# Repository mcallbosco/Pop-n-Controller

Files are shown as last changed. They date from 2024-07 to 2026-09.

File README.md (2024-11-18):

# Pop-n-Controller
THIS IS NOT READY. This repo focuses on the construction of a pop'n controller using a 3d printer and laser cutter. A remix of https://github.com/charcole/Dreamcast-PopnMusic

# Why did I make this
I didn't want to laser cut all the wood that charcole's project required (Especially since the size was too large for my cutter). I did however want a controller with curves. Unfortunetly, it was harder than I thought but now we are here.

# Required things for a pop'n controller of any type.
9 100mm Buttons
    1 Red
    2 Blue
    2 Green
    2 Yellow
    2 White
A Microcontroller
    I recomend the Aurduino Leonardo. It's cheap, easy to use and since our controller doesn't have additional LEDS, it's perfect for use with this controller. I would recomend using https://github.com/CrazyRedMachine/UltimatePopnController as the firmware. 
Wire
    I personally used arcade switch wires for the switches, and soldered on the wires for the lights since I didn't have any of those.

# Things required for this project
Access to a laser cutter
    This is required for the top bit. This could be modified to use 3D printed parts that are segmented, and now that I think about that I probably should add that as an option. But for now, you need a laser cut top part. The top should be made out of a sturdy material, but I got by with 1/8th inch thick ultility board. 
Access to a larger 3D printer.
    I used a neptune 4 plus, and some things hardly managed to fit on the plate. 
That's it
    We will be printing our own bolts/nuts to use, this may seem like a bad idea but it's worked well for my builds of this project. If you want to, you could change the height of the walls and make it compatable with metal bolts/nuts you can get on ebay. This project uses M8 spec nuts and bolts. 

# What should I Print/Make
    Follow the readme in the Things To Make folder.

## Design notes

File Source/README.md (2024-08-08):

Congrats, you want to build upon or modify this project to make it better. Here's a few things you should know.

# Sorry about the mess. This code is very messy, but hopefully most of the things you want to change are avalible as paramaters.
# This code is also extremly unoptimized. Usage of the OpenSCAD nightly is basically required. Enable Manifold. 

# Wall Thickness
# Due to the way I imported the walls, the walls are not 1 to 1 and not evenly thick on all parts. Sorry about this.

# Height Changes
# The bolts should automatically be compensated when you change the height, but I would recomend printing a test one to make sure before going all out.

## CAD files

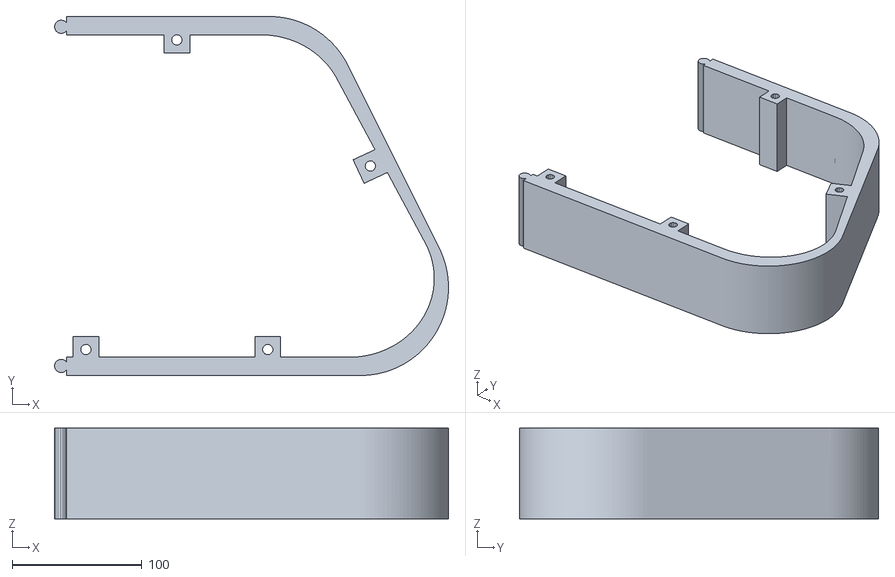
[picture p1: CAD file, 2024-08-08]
Things To Make/Wall3.stl
303.5 x 276.5 x 70.0

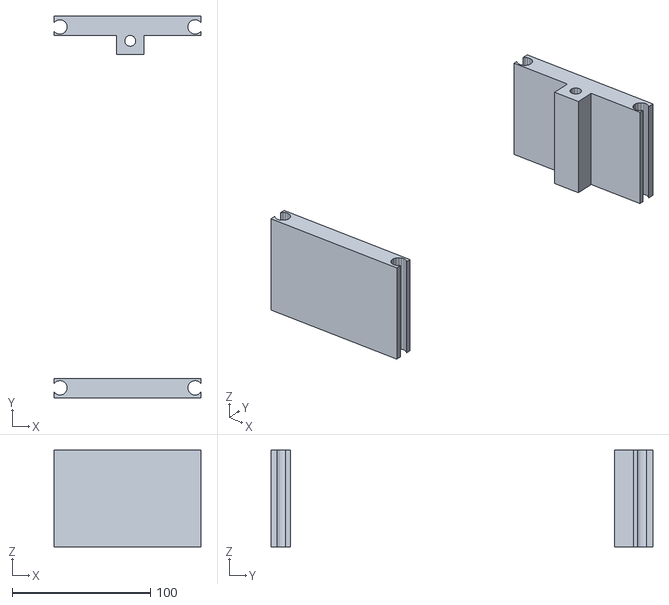
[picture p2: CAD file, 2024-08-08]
Things To Make/Wall2.stl
106.1 x 276.5 x 70.0

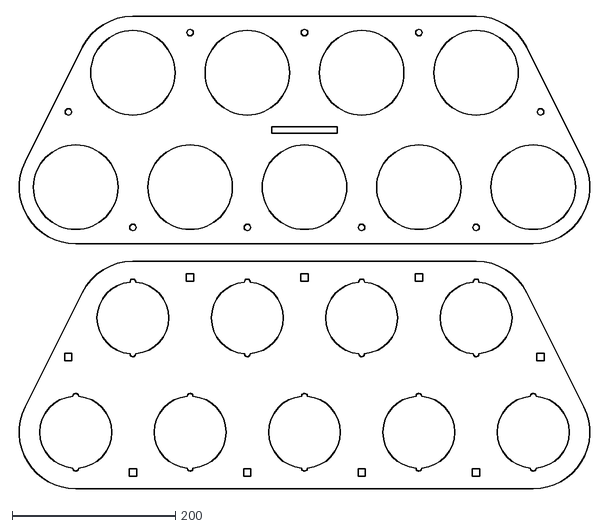
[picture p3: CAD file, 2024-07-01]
Things To Make/PopnMusicTop(OG).dxf
705.3 x 578.5

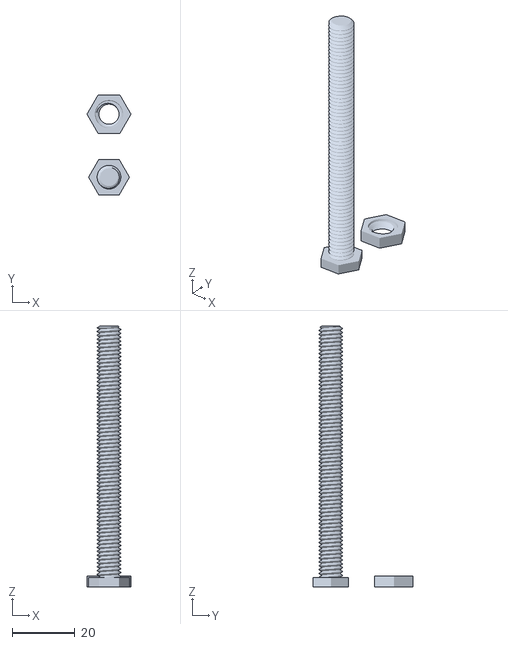
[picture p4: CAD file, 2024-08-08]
Things To Make/NutBolt.stl
14.0 x 31.7 x 82.9

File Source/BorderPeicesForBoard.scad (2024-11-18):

//Outer Shell Generation
mode = 3;
difference(){
union(){
union(){
   for (i = [0:.6:10]){
      //use the imported svg file to generate the wall
      translate([349.2335,138.2555,0]) linear_extrude(.2)
      resize([698.466-i,276.511-(i*.5),0], auto = true)
   import (file = "RefrenceForSpacerSCADdontMake.svg", convexity=3,center = true);

   }
    
    
}
union(){
   for (i = [0:.6:3]){
      //use the imported svg file to generate the wall
      translate([349.2335,138.2555,-4]) linear_extrude(4.2)
      resize([698.466+i,276.511+(i*1.3),0], auto = true)
   import (file = "RefrenceForSpacerSCADdontMake.svg", convexity=3,center = true);

   }
    
    
}
}
union(){
   for (i = [0:.6:.6]){
      //use the imported svg file to generate the wall
      translate([349.2335,138.2555,-2.4+.5]) linear_extrude(.4)
      resize([698.466+i,276.511+(i*1.3),0], auto = true)
   import (file = "RefrenceForSpacerSCADdontMake.svg", convexity=3,center = true);

   }}
   union(){
   for (i = [0:.6:.12 ]){
      //use the imported svg file to generate the wall
      translate([349.2335,138.2555,-2.3+.2]) linear_extrude(.2)
      resize([698.466+i,276.511+(i*1.3),0], auto = true)
   import (file = "RefrenceForSpacerSCADdontMake.svg", convexity=3,center = true);

   }}
union(){
   for (i = [0:.6:1.5]){
      //use the imported svg file to generate the wall
      translate([349.2335,138.2555,-1.5]) linear_extrude(1.5)
      resize([698.466+i,276.511+(i*1.3),0], auto = true)
   import (file = "RefrenceForSpacerSCADdontMake.svg", convexity=3,center = true);

   }}
   if (mode == 1){
translate([279.235+15,-10,-10]) cube ([1000,500,1000]);}
if (mode == 2){
translate([-2,-10,-10]) cube ([279.235+15+2,500,1000]); 
    translate([400.295,-10,-10]) cube ([1000,500,1000]); }
if (mode == 3){
translate([-3,-10,-10]) cube ([400.295+3,500,1000]); 

}
}
    
    
    
    

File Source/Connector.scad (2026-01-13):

// Connector.scad
// Universal connector for joining parts
// Shape: U-channel (Box without top and two faces) with side ridges.

// Generates the 2D profile of the connector (U-shape with side ridges)
module connector_profile(width, height, wall_thickness, base_thickness, ridge_depth) {
    w = width;
    h = height;
    wt = wall_thickness;
    bt = base_thickness;
    rd = ridge_depth;
    
    // Centered on X, Bottom at Y=0 (in 2D) -> Z=0 in 3D
    // U-shape body
    difference() {
        translate([-w/2, 0]) square([w, h]);
        translate([-w/2 + wt, bt]) square([w - 2*wt, h + 0.1]); // +0.1 to ensure top cut
    }
}

// Generates the 3D connector object
module UniversalConnector(length=20, width=8, height=4, wall_thickness=2.5, base_thickness=3.0, ridge_depth=0.5, tolerance=0) {
    // Apply tolerance to shrink the connector slightly if needed
    // Usually tolerance is 0 for the part, and >0 for the hole.
    
    eff_w = width - tolerance;
    eff_h = height - tolerance;
    eff_l = length - tolerance; 
    
    // Extrude along Y
    rotate([-90, 0, 0])
    linear_extrude(height=eff_l, center=true)
        connector_profile(eff_w, eff_h, wall_thickness, base_thickness, ridge_depth);
}

// Generates the negative volume to subtract from the parts
module UniversalConnectorCutout(length=20, width=8, height=4, wall_thickness=2.5, base_thickness=3.0, ridge_depth=0.5, tolerance=0.2) {
    // Cutout is larger by tolerance
    eff_w = width + tolerance;
    eff_h = height; // Height usually matches surface, or +tolerance if embedded
    eff_l = length + tolerance;
    
    // Extrude along Y
    rotate([-90, 0, 0])
    linear_extrude(height=eff_l, center=true)
    connector_profile(eff_w, eff_h, wall_thickness, base_thickness, ridge_depth);
}

// ===================================
// == Z-Pillar and Tab Modules
// ===================================

// A vertical tab that protrudes from the face of a part (Z direction)
// Designed as a radial spoke.
// centered at origin locally, but positioned radially.
module ZTab(width=8, thickness=3, height=8, angle=0, distance=8) {
    // width: Radial length of the tab
    // thickness: Tangential thickness
    // distance: Radial distance from center to center of tab
    // angle: Angle in XY plane
    
    rotate([0, 0, angle])
    translate([distance, 0, 0])
    linear_extrude(height=height, scale=[0.9, 0.9]) // Slight taper for fit
        square([width, thickness], center=true);
}

// The Hub/Pillar that accepts the tabs
// Centered at the intersection point.
module PillarBlock(height=10, radius=14, tab_width=8, tab_thickness=3, tab_dist=8, tolerance=0.3) {
    difference() {
        // Main body - Octagon for style or Cylinder
        cylinder(r=radius, h=height, $fn=8);
        
        // Subtract slots for tabs at 45, 135, 225, 315
        // Add tolerance to the slot
        for (a = [45, 135, 225, 315]) {
             // Slot is slightly larger than tab
             ZTab(width=tab_width + tolerance, thickness=tab_thickness + tolerance, height=height+1, angle=a, distance=tab_dist);
        }
        
        // Central hole for looks or reinforcement?
        // cylinder(r=4, h=height*3, center=true, $fn=16);
    }
}

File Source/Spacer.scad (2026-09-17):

use <Connector.scad>

//=====================================================================
//== Configuration for Splitting and Printing
//=====================================================================

// Set which part to render for export.
// Part 0:     ALL PARTS - Assembly view showing all parts at once
// Bottom Row: 1=Left, 2=Mid-Left, 3=Middle, 4=Mid-Right, 5=Right
// Top Row:    6=Left, 7=Mid-Left, 8=Mid-Right, 9=Right
// Part 10 is the printable connector.
// Part 11 is a test wall connector rail (for fit testing).
part_to_render = 0; // [0:11]

// Assembly view spacing (only used when part_to_render = 0)
// Set to 0 to see parts fully assembled, increase to separate them
assembly_spacing = 10; // Gap between parts in mm

// --- Main Dimensions ---
// Set bottom_plate_mode to true for a simple 5mm plate with no button holes.
bottom_plate_mode = true;

main_wall_height = 70;
main_bottom_height = 8;

wall_thickness = 18; 
wall_height = bottom_plate_mode ? 5 : main_wall_height;
bottom_height = bottom_plate_mode ? 5 : main_bottom_height;

// Locating lip on the wall, with a matching groove in the removable plate.
locating_lip_enabled = true;
locating_lip_height = 1.5;
locating_lip_width = 1.5;
locating_lip_inset = 1.2;     // Outer edge of lip measured from body perimeter
locating_lip_clearance = 0.3; // Clearance on EACH side of the lip
locating_lip_depth_clearance = 0.2;

total_x = 698.466;
total_y = 276.511;
total_z = max(100, wall_height + locating_lip_height + 1, bottom_height + 1);


wall_cuts = [[139.239, 279.235, 419.231, 559.228],
             [209.237, 349.233, 489.230]];
plate_cut_shift = 15;
cut_shift = bottom_plate_mode ? plate_cut_shift : 0;
row_cuts = [for (row = wall_cuts) [for (x = row) x + cut_shift]];
y_cut1 = total_y / 2;

function part_row(part) = part <= 5 ? 0 : 1;
function part_index(part) = part <= 5 ? part - 1 : part - 6;
function row_edges(row) = concat([0], row_cuts[row], [total_x]);
function get_seam_y(x) =
    x < row_cuts[1][0] || x >= row_cuts[1][2] ? y_cut1 - 4 : y_cut1 + 13;

module front_row_volume() {
    // Keep seam faces in 3D: a 2D polygon rounds coordinates before extrusion,
    // which can leave a microscopic gap where a dovetail meets the seam.
    bands = [0, row_cuts[1][0], row_cuts[1][2], total_x];
    for (i = [0:2])
        translate([bands[i], 0, 0])
            cube([bands[i + 1] - bands[i],
                  y_cut1 + (i == 1 ? 13 : -4), total_z]);
}

module part_volume(part) {
    row = part_row(part);
    index = part_index(part);
    edges = row_edges(row);
    intersection() {
        translate([edges[index], 0, 0])
            cube([edges[index + 1] - edges[index], total_y, total_z]);
        if (row == 0) front_row_volume();
        else difference() {
            cube([total_x, total_y, total_z]);
            front_row_volume();
        }
    }
}

// --- Connector Parameters ---
conn_len = 30;
conn_width = 10;
conn_height = 5;
conn_z_pos = bottom_height + (bottom_plate_mode ? 1 : 0); // Flush with top of plate, shifted 1mm up in bottom_plate_mode

// Seam connector positions
conn_middle_x_positions = [70, 100, 140, 175, 210, 245, 280, 315, 350,
                           385, 420, 455, 490, 525, 560, 595, 630];
conn_bottom_y_positions = [45, 110];
conn_top_y_positions = [180, 235];

// --- Wall Connector Parameters (Dovetail Rail/Slot) ---
wall_rail_height = wall_height; // Matches wall height
wall_rail_base = 8;          // Widest part of the dovetail
wall_rail_tip = 4;           // Narrowest part of the dovetail (at the neck)
wall_rail_depth = 4;         // Length of the dovetail pin
wall_rail_tolerance = 0.3;   // Clearance for 3D printing fit
wall_center_offset = 7;      // Distance from outer wall edge to center of connector
side_wall_offset = 32;       // Fixed side connector X offset; check if thickness changes
side_wall_rail_base = 6;     // Smaller base for side walls
side_wall_rail_tip = 3;      // Smaller tip for side walls

// --- USB Connector Hole Parameters ---
usb_hole_diameter = 24;      // Diameter of the USB connector hole (in mm)
usb_x_pos = 330;             // X position (centered on the model by default)
usb_z_pos = 40;              // Z position (height from the bottom, centered on wall)

// D-Type screw hole parameters (Neutrik D-series)
usb_screw_hole_diameter = 3.4; // Diameter for M3 heat-set inserts
usb_screw_x_spacing = 19;      // Horizontal distance between screw centers
usb_screw_z_spacing = 24;      // Vertical distance between screw centers

// Module to create USB connector hole cutout on the back wall
module usb_connector_hole() {
    // Extend beyond the inside wall so the socket always cuts through.
    wall_y = total_y;
    cut_depth = max(30, wall_thickness + 2);
    
    // Main 24mm opening
    translate([usb_x_pos, wall_y - cut_depth/2, usb_z_pos])
    rotate([90, 0, 0])
    cylinder(h = cut_depth, d = usb_hole_diameter, center = true, $fn = 64);

    // D-Type mounting holes (diagonal pair 1: top-left and bottom-right)
    // Horizontal offset: 19/2 = 9.5mm, Vertical offset: 24/2 = 12mm
    for (offset = [[-usb_screw_x_spacing/2, usb_screw_z_spacing/2], 
                   [usb_screw_x_spacing/2, -usb_screw_z_spacing/2]]) {
        translate([usb_x_pos + offset[0], wall_y - cut_depth/2, usb_z_pos + offset[1]])
        rotate([90, 0, 0])
        cylinder(h = cut_depth, d = usb_screw_hole_diameter, center = true, $fn = 32);
    }
}


// --- Magnet Hole Parameters ---
magnet_enabled = true;
magnet_diameter = 6.2;
magnet_depth = 2;
magnet_pitch = 40;             // Approximate pitch before seam exclusions
magnet_end_margins = [90, 165]; // Keep pockets on the straight front/back walls
magnet_edge_clearance = 2;     // Minimum material around a pocket
magnet_seam_clearance = 12;    // Minimum center distance from BOTH sets of cuts
magnet_row_inset = wall_thickness / 2;

function magnet_x_positions(row) =
    let(start = magnet_end_margins[row], end = total_x - start,
        intervals = max(1, floor((end - start) / magnet_pitch)),
        keepout = max(magnet_seam_clearance,
                      magnet_diameter / 2 + magnet_edge_clearance +
                      wall_rail_depth + wall_rail_tolerance / 2),
        seams = concat(wall_cuts[row],
                       [for (x = wall_cuts[row]) x + plate_cut_shift]))
    [for (i = [0:intervals])
        let(x = start + (end - start) * i / intervals)
        if (min([for (cut = seams) abs(x - cut)]) >= keepout) x];

magnet_positions = [for (row = [0:1], x = magnet_x_positions(row))
    [x, row == 0 ? magnet_row_inset : total_y - magnet_row_inset]];

module magnet_holes() {
    if (magnet_enabled) {
        assert(magnet_pitch > 0 && magnet_diameter > 0 && magnet_depth > 0);
        assert(magnet_depth < (bottom_plate_mode ? bottom_height : wall_height));
        assert(magnet_row_inset >= magnet_diameter / 2 + magnet_edge_clearance,
            "Wall is too thin for these magnet pockets.");
        assert(!locating_lip_enabled ||
            magnet_row_inset - magnet_diameter / 2 >= locating_lip_inset +
            locating_lip_width + locating_lip_clearance + magnet_edge_clearance,
            "Magnet pockets are too close to the locating groove.");
        for (position = magnet_positions)
            translate([position[0], position[1], wall_height - magnet_depth])
                cylinder(d = magnet_diameter, h = magnet_depth + 0.1, $fn = 32);
    }
}

// --- Adhesive feet on the OUTSIDE of the removable bottom plate ---
// For nominal 20 mm round pads, 3–5 mm thick.
feet_enabled = true;
foot_recess_diameter = 20.6;
foot_recess_depth = 1;
foot_edge_margin = 1.2;
foot_feature_clearance = 2;
foot_row_inset = foot_recess_diameter / 2 + foot_edge_margin;
// Deliberately staggered to clear both sets of seams and the magnet pattern.
foot_x_positions = [[110, 320, total_x - 110], [181, 380, total_x - 181]];
foot_positions = [for (row = [0:1], x = foot_x_positions[row])
    [x, row == 0 ? foot_row_inset : total_y - foot_row_inset]];
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

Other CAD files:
Things To Make/PopnMusicTop(MORE ARCADE ACCURATE).dxf
Things To Make/Wall1.stl
Source/threads-library-by-cuiso-v1.scad

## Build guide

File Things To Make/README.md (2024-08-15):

Congrats on getting here. This is what you need to print/make

Laser Cutter:
PopnMusicTop.dxf #If you are using the default files, I would recomend making this with 1/8th inch thick material. If you change this, you need to change the length of the bolt. In my builds, I use wood. 

3D Printer: #Fair warning, you will need a big printer. I used a Neputne 4 Plus.
# Please note that these models expect you to have a printer that can print wiht a Tolerance of .1 mm. If your printer can't do that, you will need to re-export these files. 
Wall1.stl   x1
Wall2.stl   x1
Wall3.stl   x1
Bottom.stl  x1 #You will need to cut this, and depending on your printer size print it vertically. In my experince for some reason when I cut this it increases the length twords the center, so you may need to use a table saw to slightly cut this part.  
NutBolt.stl x8 

## Side Notes
I have made a diffrent version of PopnMusicTop.dfx that features the mesurements from (https://github.com/CrazyRedMachine/PopnPanel). Besides being more arcade accurate, that also makes this compatible with his graphics.

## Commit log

2024-07-01 Focusing on the construction
    [PopnMusic9Top2.dxf, Spacer.scad]
2024-08-15 Arcade Accurate Top
    [PopnMusicTop(MORE ARCADE ACCURATE).dxf, PopnMusicTop(OG).dxf]
2024-11-18 Forgot I finished this
    [BorderPeicesForBoard.scad]
2026-09-17 Finally cleaning this up
    [Spacer.scad]
